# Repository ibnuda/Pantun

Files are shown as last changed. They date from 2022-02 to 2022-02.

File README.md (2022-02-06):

# Pantun

A Prime-E / 40% Alice-style keyboard for IMKG Joglosemarkarto Chapter.

## About the name
Pantun (Jawi: ڤنتون) is a Malay oral poetic form used to express intricate ideas and emotions.
It is generally consists of even-numbered lines and based on ABAB rhyming schemes.

## My plea
If somehow you fabricate this design, I hope that you feed a filling meal to one
of your less-fortunate neighbours.

## License
CERN Open Hardware Licence Version 2 - Strongly Reciprocal

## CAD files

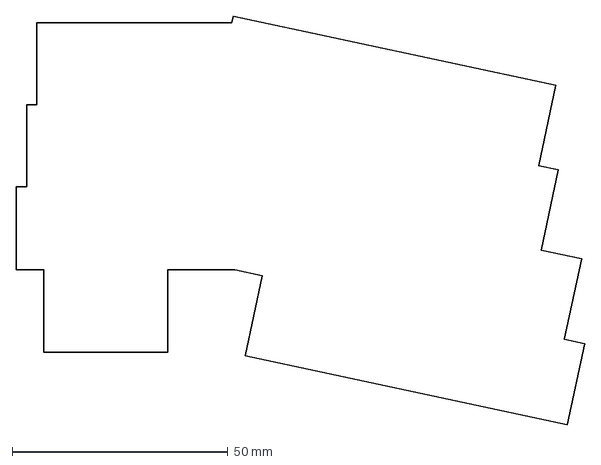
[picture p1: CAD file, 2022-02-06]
case/caps-area-left.dxf
131.7 x 94.5 mm

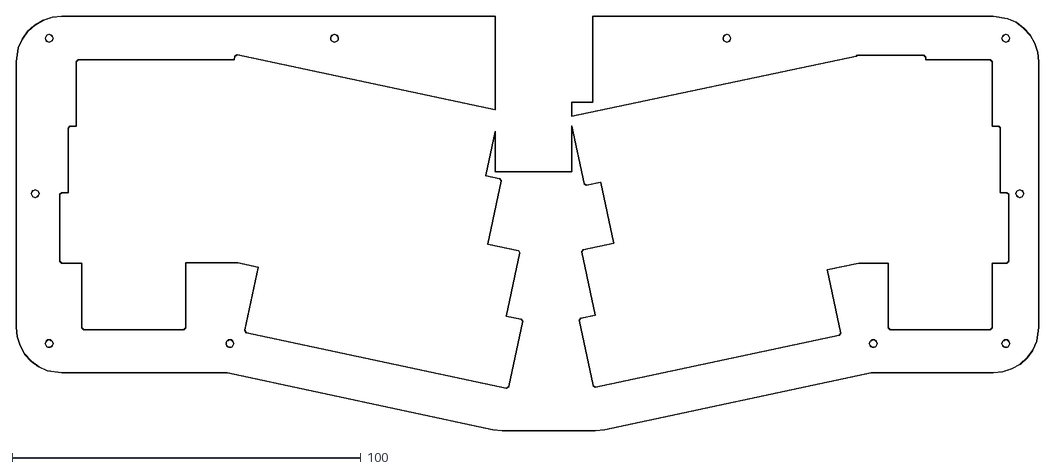
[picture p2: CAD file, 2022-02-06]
case/v1/second-1.dxf
293.3 x 118.8

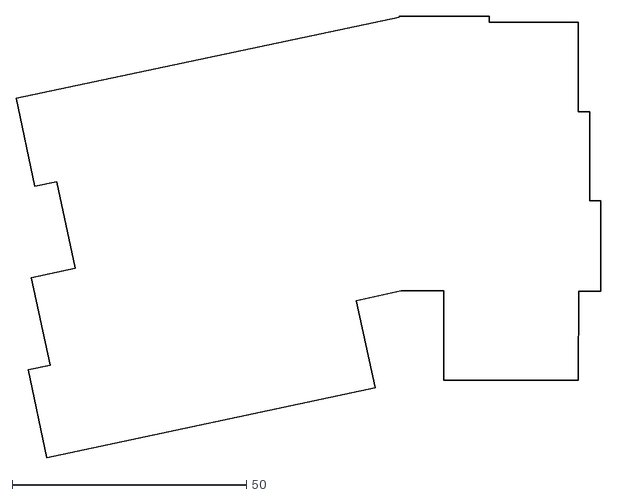
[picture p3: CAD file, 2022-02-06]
case/caps-area-right.dxf
124.7 x 94.2

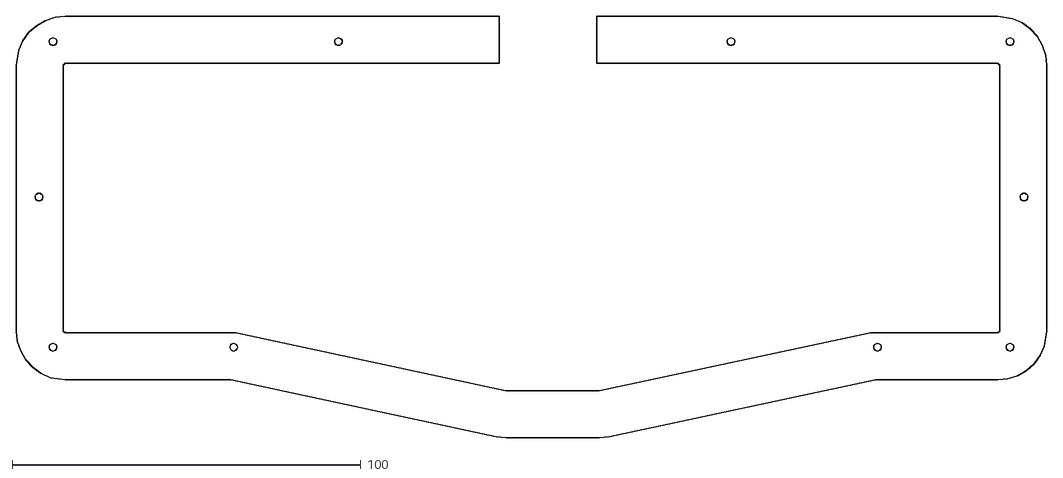
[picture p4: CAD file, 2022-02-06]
case/v1/mid-2.dxf
295.3 x 120.8

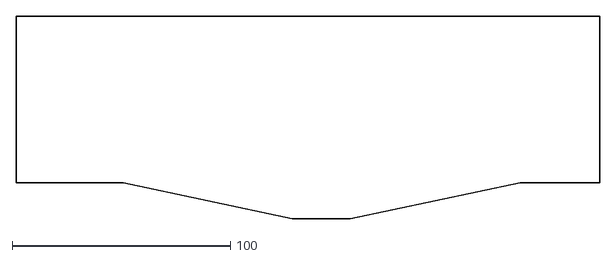
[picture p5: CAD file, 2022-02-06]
case/pcb-shape.dxf
267.3 x 92.8

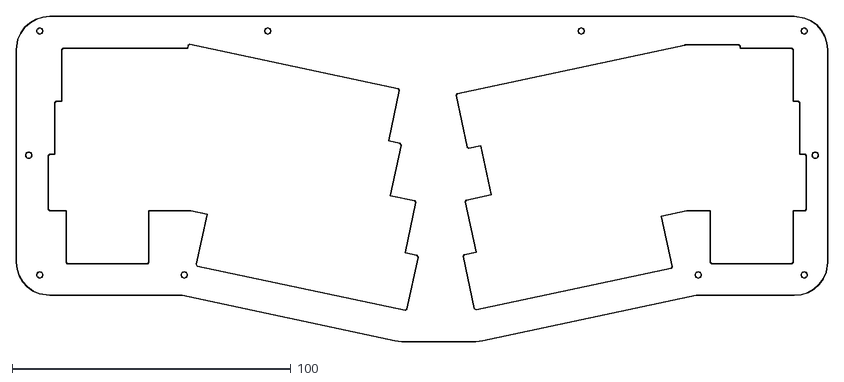
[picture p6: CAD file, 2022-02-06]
case/v1/top.dxf
291.3 x 116.8

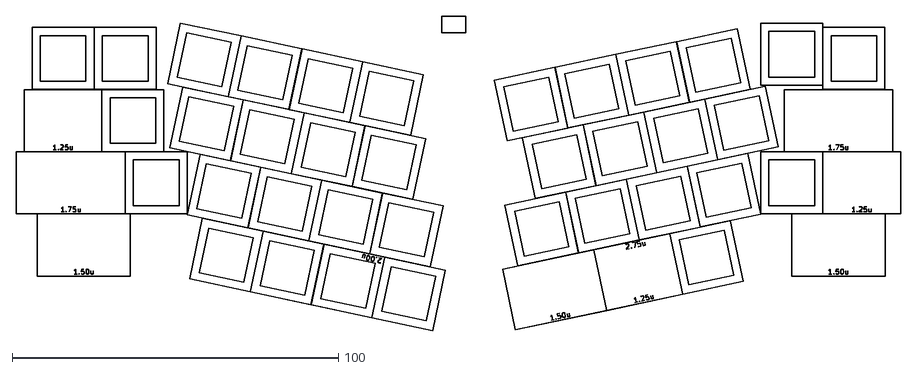
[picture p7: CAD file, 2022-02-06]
case/drawing.dxf
271.0 x 96.3

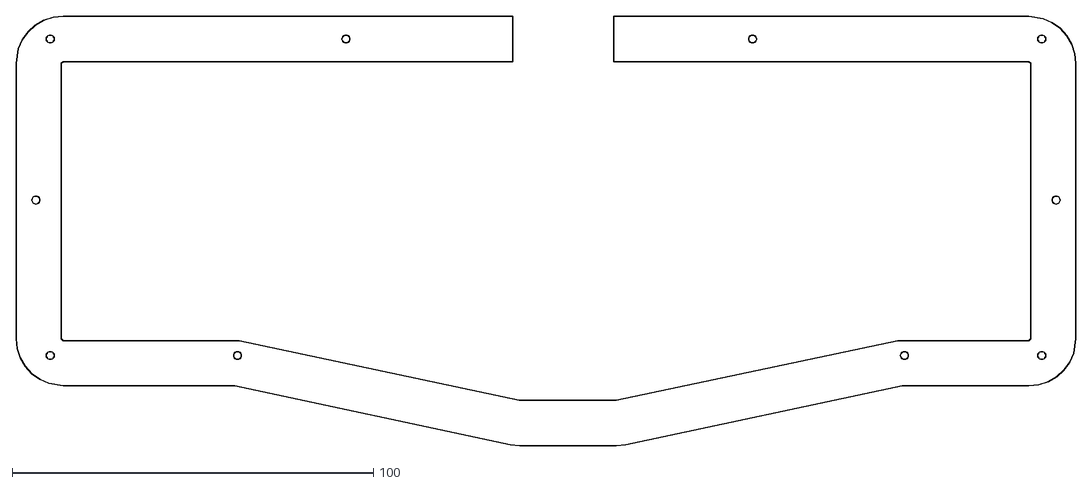
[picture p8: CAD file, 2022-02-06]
case/v1/mid-1.dxf
293.3 x 118.8

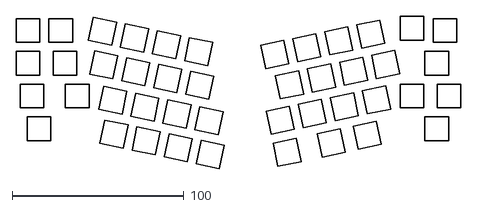
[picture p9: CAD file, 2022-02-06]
case/switch-holes.dxf
258.6 x 88.5

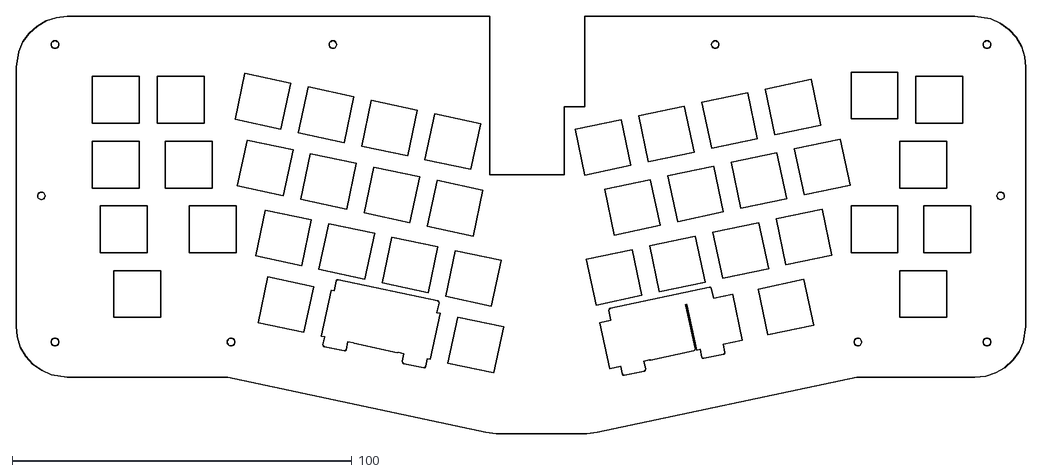
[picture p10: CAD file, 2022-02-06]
case/v1/switch.dxf
297.3 x 122.8

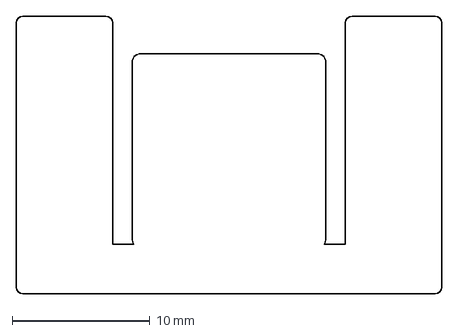
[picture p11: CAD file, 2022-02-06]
case/2u-keebio.dxf
30.9 x 20.2 mm

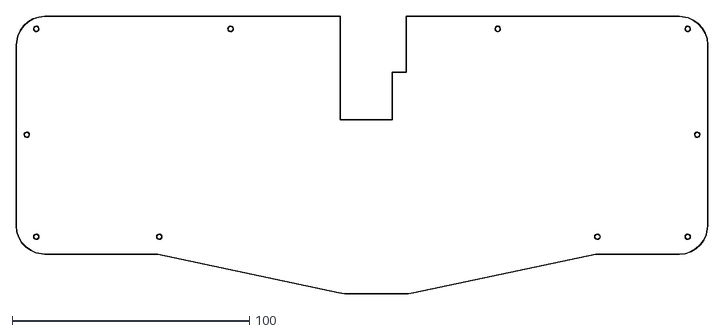
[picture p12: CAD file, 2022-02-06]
case/v1/bottom.dxf
291.3 x 116.8

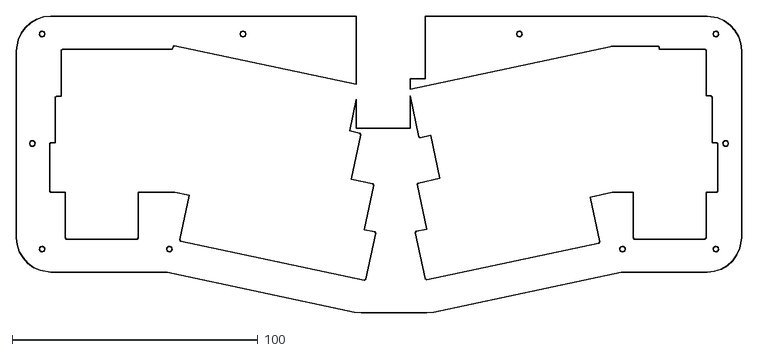
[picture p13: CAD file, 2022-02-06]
case/v1/second-2.dxf
295.3 x 120.8

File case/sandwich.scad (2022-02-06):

screw_locations = [
    [ -7.90468,  6.28256 ],
    [ 73.90468,  6.28256 ],
    [ 186.425,  6.28256 ],
    [ 266.425,  6.28256 ],
    [ -11.90468,  -38.28256 ],
    [ -7.90468,  -81.28256 ],
    [ 266.425,  -81.28256 ],
    [ 270.425,  -38.28256 ],
    [ 43.90468,  -81.28256 ],
    [ 228.425,  -81.28256 ],
];

module
screw_holes()
{
    for (i = [0:len(screw_locations) - 1]) {
        translate(screw_locations[i]) circle(r = 1.1, $fn = 20);
    }
}

module
base_shape(val = 15)
{
    offset(val) import("pcb-shape.dxf");
}

module
pcb_shape()
{
    offset(0.5) import("pcb-shape.dxf");
}

module
caps_area()
{
    union() {
        offset(0.5) import("caps-area-left.dxf");
        offset(0.5) import("caps-area-right.dxf");
    }
}

module 2u()
{
    union()
    {
        color("red") translate([ -19.05, 9.525, 0 ]) import("2u-keebio.dxf");
    }
}

module
switch_holes()
{
    union()
    {
        import("switch-holes.dxf");
        // right spacebar.
        translate([ 172.281514, -78.423288 ]) rotate([ 0, 0, 192 ]) 2u();
        // left spacebar.
        translate([ 87.982678, -76.212569 ]) rotate([ 0, 0, 168 ]) 2u();
    }
}

module
promicro_and_reset_area()
{
    polygon(points = [
        [ 120, 30 ],
        [ 120, -32 ],
        [ 142, -32 ],
        [ 142, -12 ],
        [ 148, -12 ],
        [ 148, 30 ],
    ]);
}

module
base_plate(val = 15)
{
    difference()
    {
        base_shape(val);
        screw_holes();
    }
}

module
bottom_plate(val = 15)
{
    difference()
    {
        base_shape(val);
        screw_holes();
        promicro_and_reset_area();
    }
}

module
back_feet_3(val = 15)
{
    difference()
    {
        intersection()
        {
            base_shape(val);
            translate([ -40, -80, 0 ])
                square(size = [ 400, 600 ], center = false);
        }
        screw_holes();
        promicro_and_reset_area();
    }
}

module
back_feet_2(val = 15)
{
    difference()
    {
        intersection()
        {
            base_shape(val);
            translate([ -40, -50, 0 ])
                square(size = [ 400, 600 ], center = false);
        }
        screw_holes();
    }
}

module
back_feet_1(val = 15)
{
    difference()
    {
        intersection()
        {
            base_shape(val);
            translate([ -40, -20, 0 ])
                square(size = [ 400, 600 ], center = false);
        }
        screw_holes();
    }
}

module
back_feet_0()
{
    difference()
    {
        intersection()
        {
            base_shape();
            translate([ -40, 10, 0 ])
                square(size = [ 400, 600 ], center = false);
        }
        screw_holes();
    }
}

module
middle_plate(val = 15)
{
    difference()
    {
        base_plate(val);
        pcb_shape();
        promicro_and_reset_area();
    }
}

module
switch_plate(val = 15)
{
    difference()
    {
        base_plate(15);
        promicro_and_reset_area();
        switch_holes();
    }
}

module
second_plate(val = 15)
{
    difference()
    {
        base_plate(val);
        caps_area();
        promicro_and_reset_area();
    }
}

module
top_plate(val = 15)
{
    difference()
    {
        base_plate(val);
        caps_area();
    }
}

rotate([ 6, 0, 0 ]) translate([ 0, 0, 9 ]) union()
{
    //  translate([ 0, 0, -12]) color("blue")  linear_extrude(height = 3) back_feet_0();
     translate([ 0, 0, -9 ]) color("red")   linear_extrude(height = 3) back_feet_1(11);
     translate([ 0, 0, -6 ]) color("green") linear_extrude(height = 3) back_feet_2(11);
     translate([ 0, 0, -3 ]) color("blue")  linear_extrude(height = 3) back_feet_3(11);
     translate([ 0, 0, 0 ])  color("green") linear_extrude(height = 3) bottom_plate(12);
     translate([ 0, 0, 3 ])  color("blue")  linear_extrude(height = 3) middle_plate(13);
     translate([ 0, 0, 6 ])  color("red")   linear_extrude(height = 3) middle_plate(14);
     translate([ 0, 0, 9 ])  color("black") linear_extrude(height = 3) switch_plate(15);
     translate([ 0, 0, 12 ]) color("blue")  linear_extrude(height = 3) second_plate(14);
     translate([ 0, 0, 15 ]) color("red")   linear_extrude(height = 3) second_plate(13);
     translate([ 0, 0, 18 ]) color("green") linear_extrude(height = 3) top_plate(12);
}


// translate([0, 0, 0])    bottom_plate();
// translate([0, -150, 0]) middle_plate();
// translate([0,  0,   0]) middle_plate();
// translate([0,  150, 0]) switch_plate();
// translate([0,  300, 0]) top_plate();
// translate([0,  450, 0]) top_plate();
// translate([0,  580, 0]) back_feet_3();
// translate([0,  680, 0]) back_feet_2();
// translate([0,  780, 0]) back_feet_1();
// translate([0,  820, 0]) back_feet_0();

// bottom_plate(12);
// middle_plate(13);
// middle_plate(14);
// switch_plate(15);
// second_plate(14);
// second_plate(13);
// top_plate(12);
// back_feet_3();
// back_feet_2();
// back_feet_1();
// back_feet_0();

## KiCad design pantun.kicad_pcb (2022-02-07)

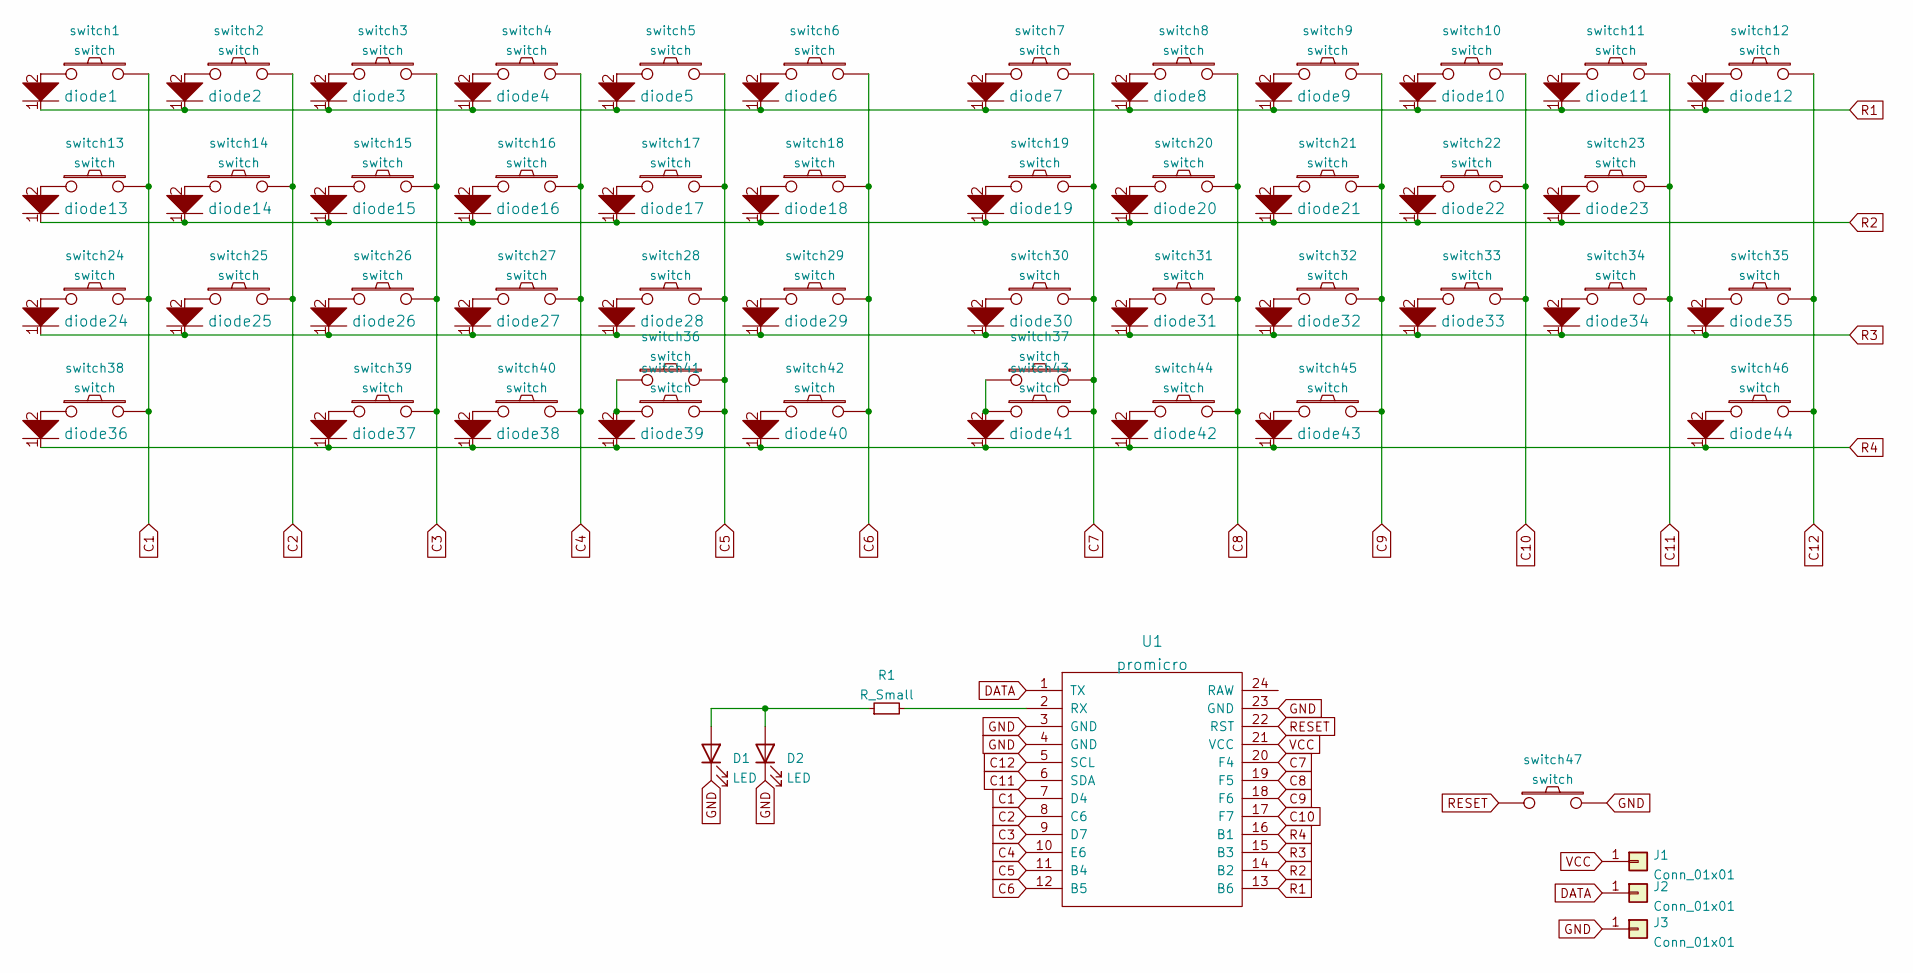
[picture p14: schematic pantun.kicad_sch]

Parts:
D1, D2: LED; LED_D2.0mm_W4.0mm_H2.8mm_FlatTop
J1, J2, J3: Conn_01x01; wirepad
R1: R_Small; R_Box_L8.4mm_W2.5mm_P5.08mm
U1: promicro; promicro-flip
diode1, diode2, diode3, diode4, diode5, diode6, diode7, diode8, diode9, diode10, diode11, diode12, diode13, diode14, diode15, diode16, diode17, diode18, diode19, diode20, diode21, diode22, diode23, diode24, diode25, diode26, diode27, diode28, diode29, diode30, diode31, diode32, diode33, diode34, diode35, diode36, diode37, diode38, diode39, diode40, diode41, diode42, diode43, diode44: diode; diode-sod-123
switch1, switch2, switch3, switch4, switch5, switch6, switch7, switch8, switch9, switch10, switch11, switch12, switch14, switch15, switch16, switch17, switch18, switch19, switch20, switch21, switch22, switch25, switch26, switch27, switch28, switch29, switch30, switch31, switch32, switch33, switch34, switch39, switch40, switch41, switch42, switch45: switch; 100-socket-solder
switch13, switch35, switch44: switch; 125-socket-solder
switch23, switch24: switch; 175-socket-solder
switch36: switch; 200-socket-solder
switch37: switch; 275-socket-solder
switch38, switch43, switch46: switch; 150-socket-solder
switch47: switch; reset

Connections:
C1: U1.7 (D4), switch1.2, switch13.2, switch24.2, switch38.2
C2: U1.8 (C6), switch2.2, switch14.2, switch25.2
C3: U1.9 (D7), switch3.2, switch15.2, switch26.2, switch39.2
C4: U1.10 (E6), switch4.2, switch16.2, switch27.2, switch40.2
C5: U1.11 (B4), switch5.2, switch17.2, switch28.2, switch36.2, switch41.2
C6: U1.12 (B5), switch6.2, switch18.2, switch29.2, switch42.2
C7: U1.20 (F4), switch7.2, switch19.2, switch30.2, switch37.2, switch43.2
C8: U1.19 (F5), switch8.2, switch20.2, switch31.2, switch44.2
C9: U1.18 (F6), switch9.2, switch21.2, switch32.2, switch45.2
C10: U1.17 (F7), switch10.2, switch22.2, switch33.2
C11: U1.6 (SDA), switch11.2, switch23.2, switch34.2
C12: U1.5 (SCL), switch12.2, switch35.2, switch46.2
DATA: J2.1, U1.1 (TX)
GND: D1.1 (K), D2.1 (K), J3.1, U1.3 (GND), U1.4 (GND), U1.23 (GND), switch47.2
unnamed: D1.2 (A), D2.2 (A), R1.1
unnamed: R1.2, U1.2 (RX)
unnamed: diode1.2, switch1.1
unnamed: diode2.2, switch2.1
unnamed: diode3.2, switch3.1
unnamed: diode4.2, switch4.1
unnamed: diode5.2, switch5.1
unnamed: diode6.2, switch6.1
unnamed: diode7.2, switch7.1
unnamed: diode8.2, switch8.1
unnamed: diode9.2, switch9.1
unnamed: diode10.2, switch10.1
unnamed: diode11.2, switch11.1
unnamed: diode12.2, switch12.1
unnamed: diode13.2, switch13.1
unnamed: diode14.2, switch14.1
unnamed: diode15.2, switch15.1
unnamed: diode16.2, switch16.1
unnamed: diode17.2, switch17.1
unnamed: diode18.2, switch18.1
unnamed: diode19.2, switch19.1
unnamed: diode20.2, switch20.1
unnamed: diode21.2, switch21.1
unnamed: diode22.2, switch22.1
unnamed: diode23.2, switch23.1
unnamed: diode24.2, switch24.1
unnamed: diode25.2, switch25.1
unnamed: diode26.2, switch26.1
unnamed: diode27.2, switch27.1
unnamed: diode28.2, switch28.1
unnamed: diode29.2, switch29.1
unnamed: diode30.2, switch30.1
unnamed: diode31.2, switch31.1
unnamed: diode32.2, switch32.1
unnamed: diode33.2, switch33.1
unnamed: diode34.2, switch34.1
unnamed: diode35.2, switch35.1
unnamed: diode36.2, switch38.1
unnamed: diode37.2, switch39.1
unnamed: diode38.2, switch40.1
unnamed: diode39.2, switch36.1, switch41.1
unnamed: diode40.2, switch42.1
unnamed: diode41.2, switch37.1, switch43.1
unnamed: diode42.2, switch44.1
unnamed: diode43.2, switch45.1
unnamed: diode44.2, switch46.1
R1: U1.13 (B6), diode1.1, diode2.1, diode3.1, diode4.1, diode5.1, diode6.1, diode7.1, diode8.1, diode9.1, diode10.1, diode11.1, diode12.1
R2: U1.14 (B2), diode13.1, diode14.1, diode15.1, diode16.1, diode17.1, diode18.1, diode19.1, diode20.1, diode21.1, diode22.1, diode23.1
R3: U1.15 (B3), diode24.1, diode25.1, diode26.1, diode27.1, diode28.1, diode29.1, diode30.1, diode31.1, diode32.1, diode33.1, diode34.1, diode35.1
R4: U1.16 (B1), diode36.1, diode37.1, diode38.1, diode39.1, diode40.1, diode41.1, diode42.1, diode43.1, diode44.1
RESET: U1.22 (RST), switch47.1
VCC: J1.1, U1.21 (VCC)

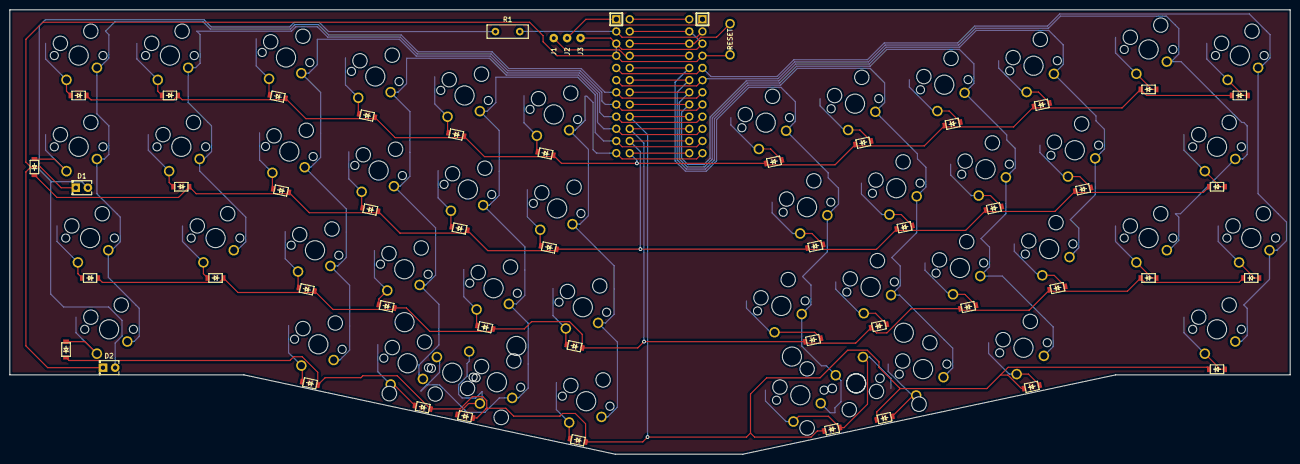
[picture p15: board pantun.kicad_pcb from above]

Board: 2 copper layers, 267.3 x 92.8 mm, 98 parts (0 on the bottom side), 66 nets.

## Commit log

2022-02-06 init commit.
    [pantun.kicad_pcb, pantun.kicad_sch]
2022-02-06 moved thumb row 1/4u to the left and added one 1u.
    [pantun.kicad_pcb, pantun.kicad_sch]
2022-02-06 added stacked acrylic plates.
    [2u-keebio.dxf, bottom.dxf, caps-area-left.dxf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]
2022-02-07 added led. lol.
    [pantun.kicad_pcb, pantun.kicad_sch]
